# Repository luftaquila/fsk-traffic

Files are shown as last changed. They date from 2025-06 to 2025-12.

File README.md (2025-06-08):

# Formula Student Korea Traffic Controller

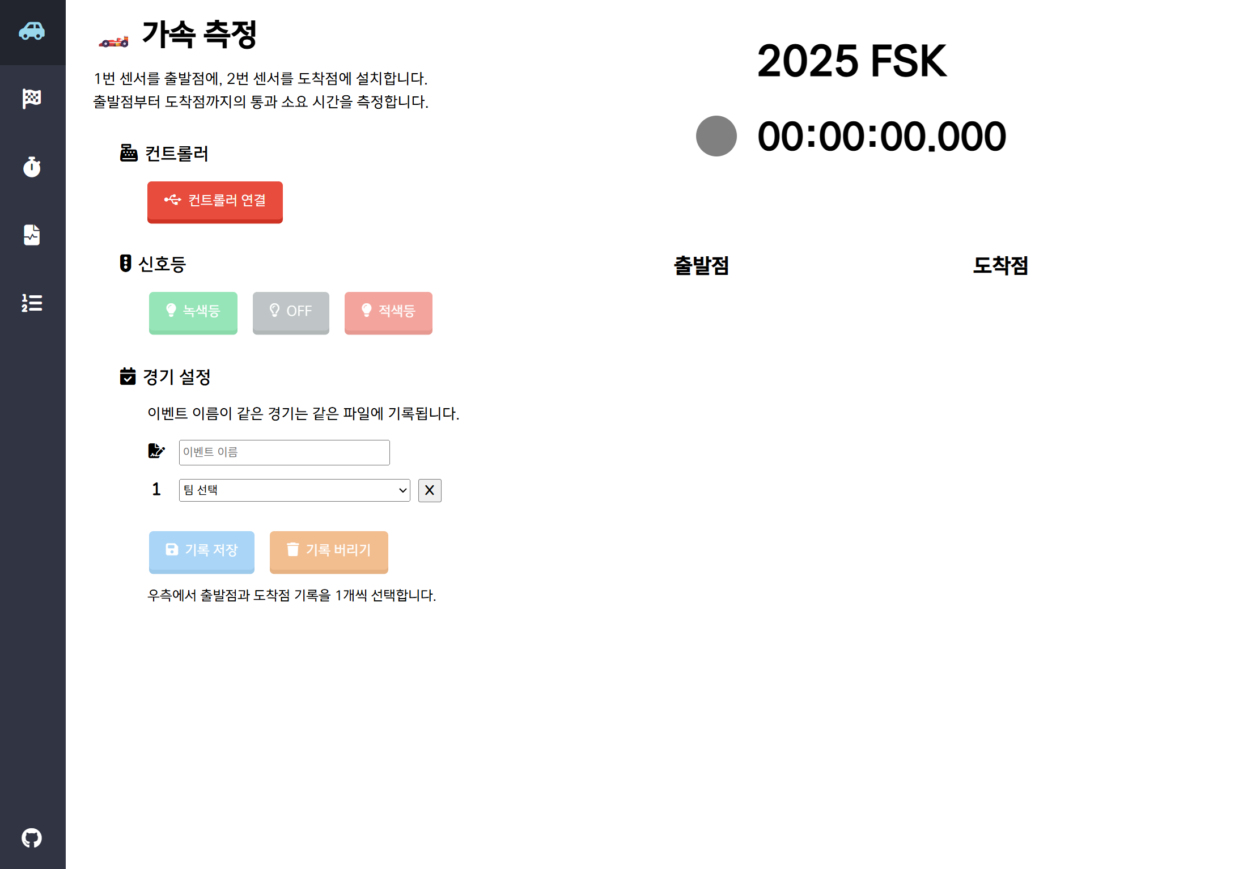
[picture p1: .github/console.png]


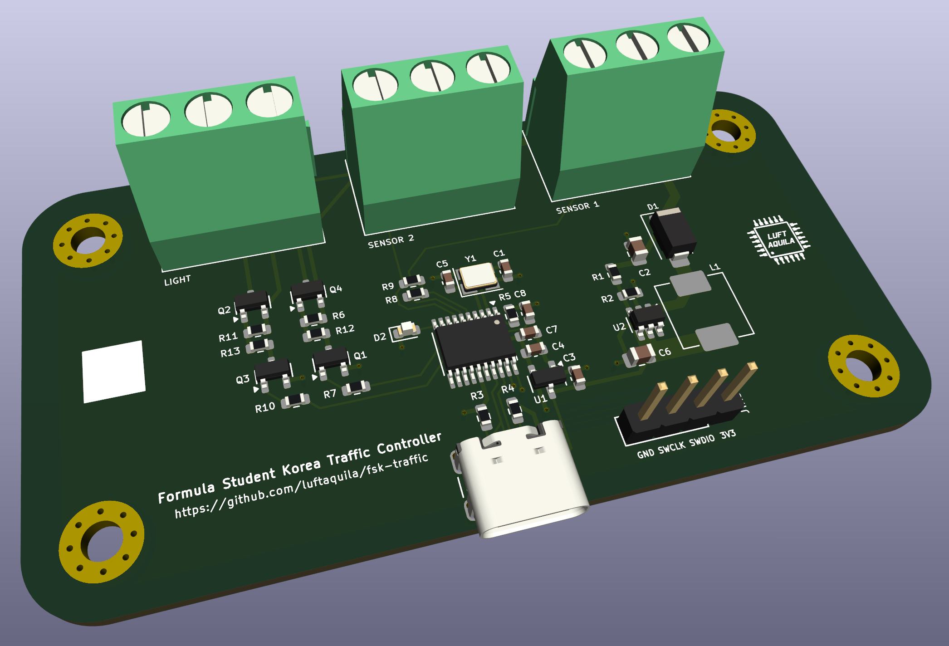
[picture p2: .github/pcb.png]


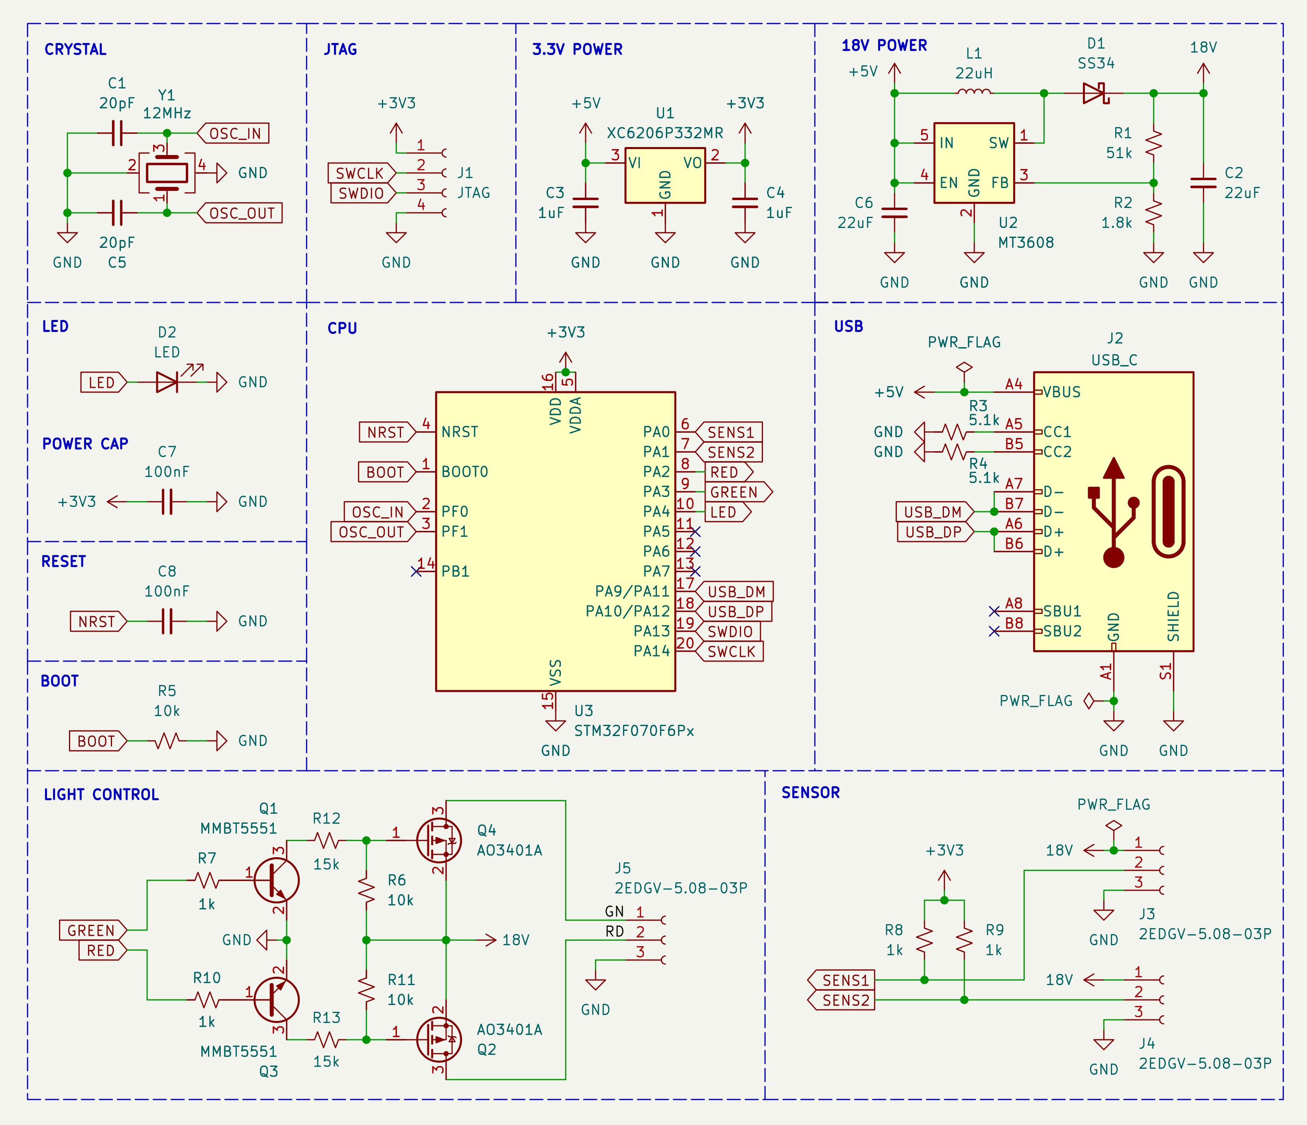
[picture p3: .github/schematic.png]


## Development

### Controller firmware

#### Prerequisites

```sh
git clone https://github.com/luftaquila/fsk-traffic.git
```

* `arm-none-eabi-gcc` ([AArch32 bare-metal target (arm-none-eabi)](https://developer.arm.com/downloads/-/arm-gnu-toolchain-downloads))
* make
* openocd

#### Build and upload

```sh
cd device/firmware
make program
```

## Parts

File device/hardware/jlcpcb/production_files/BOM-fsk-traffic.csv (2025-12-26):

Comment | Designator | Footprint | LCSC | Quantity
LTV-817S | U4,U5 | SMDIP-4_W9.53mm | C109227 | 2
100nF | C7,C8 | C_0603_1608Metric | C14663 | 2
AO3401A | Q2,Q4 | SOT-23 | C15127 | 2
1uF | C3,C4 | C_0603_1608Metric | C15849 | 2
470nF | C10,C9 | C_0603_1608Metric | C1623 | 2
20pF | C1,C5 | C_0603_1608Metric | C1648 | 2
USB_C | J2 | USB_C_Receptacle_GCT_USB4105-xx-A_16P_TopMnt_Horizontal | C165948 | 1
22uH | L1 | L_Changjiang_FXL0630 | C177244 | 1
1k | R10,R14,R7 | R_0603_1608Metric | C21190 | 3
MMBT5551 | Q1,Q3 | SOT-23 | C2145 | 2
15k | R12,R13 | R_0603_1608Metric | C22809 | 2
LED | D2 | LED_0603_1608Metric | C2286 | 1
2k | R15,R16 | R_0603_1608Metric | C22975 | 2
3.3k | R8,R9 | R_0603_1608Metric | C22978 | 2
5.1k | R3,R4 | R_0603_1608Metric | C23186 | 2
51k | R1 | R_0603_1608Metric | C23196 | 1
10k | R11,R5,R6 | R_0603_1608Metric | C25804 | 3
1.8k | R2 | R_0603_1608Metric | C4177 | 1
22uF | C2,C6 | C_0805_2012Metric | C45783 | 2
XC6206P332MR | U1 | SOT-23-3 | C5446 | 1
SS34 | D1 | D_SMA | C8678 | 1
STM32F070F6Px | U3 | TSSOP-20_4.4x6.5mm_P0.65mm | C86951 | 1
12MHz | Y1 | Crystal_SMD_3225-4Pin_3.2x2.5mm | C9002 | 1
MT3608 | U2 | SOT-23-6 |  | 1

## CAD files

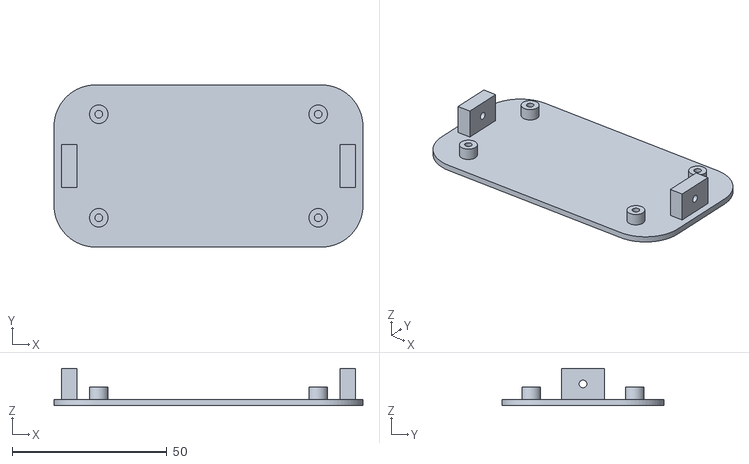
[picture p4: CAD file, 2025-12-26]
device/3d/base.stl
100.0 x 52.5 x 12.0

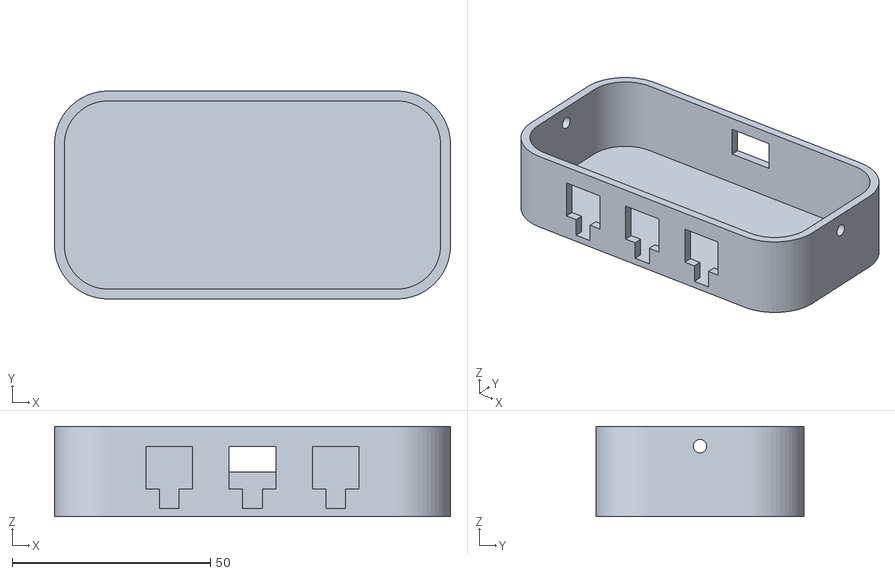
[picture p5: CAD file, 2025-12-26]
device/3d/lid.stl
100.0 x 52.5 x 22.8

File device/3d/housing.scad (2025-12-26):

// PCB Housing for 83x45.5mm board
// OpenSCAD design for 3D printing

/* [Rendering Options] */
// What to render
part = "both"; // [bottom, lid, both, assembled]

/* [PCB Dimensions] */
pcb_length = 83;        // mm
pcb_width = 45.5;       // mm
pcb_corner_r = 6;       // mm
pcb_thickness = 1.6;    // mm (standard PCB)

/* [Housing Dimensions] */
wall_thickness = 2.5;   // mm
floor_thickness = 2;    // mm
lid_thickness = 2;      // mm
pcb_clearance = 1;      // mm (gap between PCB and walls/mounting structures)

/* [Boss / Standoff] */
boss_height = 4;        // mm (PCB height from floor)
boss_outer_d = 6;       // mm
boss_inner_d = 2.5;     // mm (for M3 tap or insert)

/* [USB Type-C Port] */
usbc_width = 13;        // mm (with rubber boot clearance)
usbc_height = 7;        // mm (with rubber boot clearance)
// USB port position: 38.334mm from left, 39.566mm from right
// Offset from center = (38.334 - 39.566) / 2 = -0.616mm (shifted left)
usbc_x_offset = -0.616; // mm (negative = left when looking at port)
usbc_z_offset = -1.6;   // mm (negative = lower)

/* [Molex 5557 Connector] */
molex_width = 10.8;     // mm
molex_height = 10.2;    // mm (protrusion from wall)
molex_depth = 14;       // mm (along PCB direction)
molex_spacing = 10.2;   // mm (center to center gap between connectors)
molex_latch_extra = 5;  // mm (extra height for latch)
molex_labels = ["LIGHT", "SENS2", "SENS1"];  // labels for each connector
label_size = 3.0;       // mm (text height)
label_depth = 0.8;      // mm (engraving depth)
label_spacing = 1.2;    // character spacing (1 = normal, >1 = wider)
label_weight = -0.05;   // mm (0 = normal, + = thicker, - = thinner)

/* [Lid Mounting] */
mount_wall_width = 14;       // mm (Y direction)
mount_wall_thickness = 5;    // mm (X direction, for screw thread)
mount_wall_height = 10;      // mm (Z direction)
mount_screw_d = 2.5;         // mm (for M3 tap)

/* [Calculated Values] */
// PCB cavity (where PCB sits, with clearance all around)
pcb_cavity_length = pcb_length + pcb_clearance * 2;
pcb_cavity_width = pcb_width + pcb_clearance * 2;

// Housing dimensions (includes mounting wall space at short sides)
inner_length = pcb_cavity_length + mount_wall_thickness * 2;
inner_width = pcb_cavity_width;
outer_length = inner_length + wall_thickness * 2;
outer_width = inner_width + wall_thickness * 2;

// Height from floor to PCB top surface
pcb_top_z = boss_height + pcb_thickness;

// Total internal height
component_height = max(molex_height + molex_latch_extra, 15);
inner_height = boss_height + pcb_thickness + component_height;
outer_height = floor_thickness + inner_height + lid_thickness;

// M3 hole positions (at corner radius centers, relative to PCB center)
m3_positions = [
    [pcb_corner_r - pcb_length/2, pcb_corner_r - pcb_width/2],
    [pcb_length/2 - pcb_corner_r, pcb_corner_r - pcb_width/2],
    [pcb_corner_r - pcb_length/2, pcb_width/2 - pcb_corner_r],
    [pcb_length/2 - pcb_corner_r, pcb_width/2 - pcb_corner_r]
];

// Molex connector positions (X offset from center)
molex_positions = [
    -molex_spacing - molex_width,
    0,
    molex_spacing + molex_width
];

$fn = 64;

// ============================================
// MODULES
// ============================================

module rounded_rect(length, width, r) {
    offset(r = r)
        offset(r = -r)
            square([length, width], center = true);
}

module rounded_box(length, width, height, r) {
    linear_extrude(height)
        rounded_rect(length, width, r);
}

module boss() {
    difference() {
        cylinder(h = boss_height, d = boss_outer_d);
        cylinder(h = boss_height + 1, d = boss_inner_d);
    }
}

// ============================================
// BOTTOM PART
// ============================================

module bottom() {
    difference() {
        union() {
            // Floor plate (same size as lid)
            rounded_box(outer_length, outer_width, floor_thickness, pcb_corner_r + wall_thickness + mount_wall_thickness);
            
            // Boss standoffs for PCB
            translate([0, 0, floor_thickness]) {
                for (pos = m3_positions) {
                    translate([pos[0], pos[1], 0])
                        boss();
                }
            }
            
            // Mounting walls (inside lid walls, outside PCB cavity)
            // Left side
            translate([-pcb_cavity_length/2 - mount_wall_thickness, -mount_wall_width/2, floor_thickness])
                cube([mount_wall_thickness, mount_wall_width, mount_wall_height]);
            
            // Right side
            translate([pcb_cavity_length/2, -mount_wall_width/2, floor_thickness])
                cube([mount_wall_thickness, mount_wall_width, mount_wall_height]);
        }
        
        // Horizontal screw holes in mounting walls (threaded)
        screw_z = floor_thickness + mount_wall_height / 2;
        
        // Left wall hole
        translate([-outer_length/2 - 1, 0, screw_z])
            rotate([0, 90, 0])
                cylinder(h = wall_thickness + mount_wall_thickness + 2, d = mount_screw_d);
        
        // Right wall hole
        translate([pcb_cavity_length/2 - 1, 0, screw_z])
            rotate([0, 90, 0])
                cylinder(h = wall_thickness + mount_wall_thickness + 2, d = mount_screw_d);
    }
}

// ============================================
// LID PART
// ============================================

module lid() {
    m3_clearance = 3.4;
    screw_z = mount_wall_height / 2;
    port_margin = 0.5;  // extra clearance for ports
    
    difference() {
        union() {
            // Top plate
            translate([0, 0, inner_height])
                rounded_box(outer_length, outer_width, lid_thickness, pcb_corner_r + wall_thickness + mount_wall_thickness);
            
            // Side walls
            difference() {
                rounded_box(outer_length, outer_width, inner_height, pcb_corner_r + wall_thickness + mount_wall_thickness);
                translate([0, 0, -0.1])
                    rounded_box(inner_length, inner_width, inner_height + 0.2, pcb_corner_r + mount_wall_thickness);
            }
        }
        
        // USB Type-C port cutout (offset from center)
        // Port starts at PCB top surface and goes UP
        translate([usbc_x_offset - usbc_width/2, -outer_width/2 - 1, pcb_top_z + usbc_z_offset - port_margin])
            cube([usbc_width, wall_thickness + 2, usbc_height + port_margin * 2]);
        
        // Molex 5557 connector cutouts
        // Port starts at PCB top surface and goes UP
        molex_latch_width = 5;  // latch opening width (center only)
        for (x_pos = molex_positions) {
            // Main connector opening (full width)
            translate([x_pos - (molex_width + 1)/2, outer_width/2 - wall_thickness - 1, pcb_top_z - port_margin])
                cube([molex_width + 1, wall_thickness + 2, molex_height + port_margin]);
            
            // Latch opening (center 5mm only, exactly molex_latch_extra height)
            translate([x_pos - molex_latch_width/2, outer_width/2 - wall_thickness - 1, pcb_top_z + molex_height])
                cube([molex_latch_width, wall_thickness + 2, molex_latch_extra]);
        }
        
        // Horizontal screw holes through short side walls (clearance holes)
        // Left wall
        translate([-outer_length/2 - 1, 0, screw_z])
            rotate([0, 90, 0])
                cylinder(h = wall_thickness + 2, d = m3_clearance);
        
        // Right wall
        translate([outer_length/2 - wall_thickness - 1, 0, screw_z])
            rotate([0, 90, 0])
                cylinder(h = wall_thickness + 2, d = m3_clearance);
        
        // Molex connector labels (engraved on top surface)
        for (i = [0:2]) {
            translate([molex_positions[i], outer_width/2 - wall_thickness - 5, inner_height + lid_thickness - label_depth + 0.1])
                linear_extrude(label_depth + 0.1)
                    offset(r = label_weight)
                        text(molex_labels[i], size = label_size, spacing = label_spacing, halign = "center", valign = "center", font = "Liberation Sans:style=Bold");
        }
    }
}

// ============================================
// RENDERING
// ============================================

if (part == "bottom") {
    bottom();
}
else if (part == "lid") {
    translate([0, 0, inner_height + lid_thickness])
        rotate([180, 0, 0])
            lid();
}
else if (part == "both") {
    translate([-(outer_length/2 + 10), 0, 0])
        bottom();
    
    translate([outer_length/2 + 10, 0, inner_height + lid_thickness])
        rotate([180, 0, 0])
            lid();
}
else if (part == "assembled") {
    color("lightblue", 0.8) bottom();
    
    color("lightyellow", 0.8)
    translate([0, 0, floor_thickness])
        lid();
}

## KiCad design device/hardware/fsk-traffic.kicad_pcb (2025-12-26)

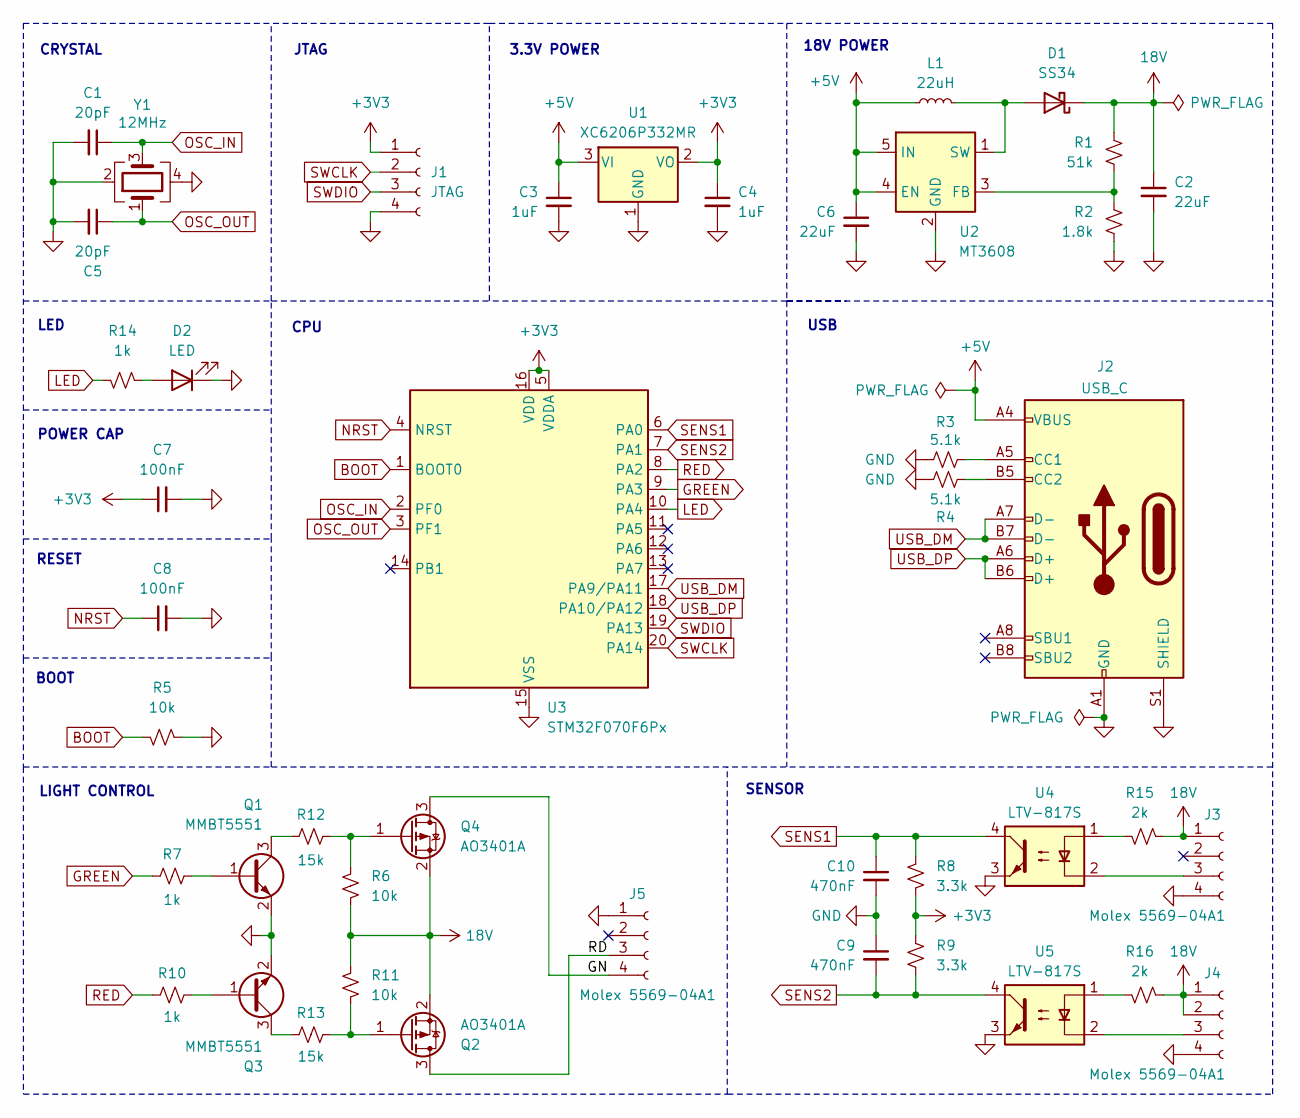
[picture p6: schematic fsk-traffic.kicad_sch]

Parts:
C1, C5: 20pF; C_0603_1608Metric; LCSC C1648
C2, C6: 22uF; C_0805_2012Metric; LCSC C45783
C3, C4: 1uF; C_0603_1608Metric; LCSC C15849
C7, C8: 100nF; C_0603_1608Metric; LCSC C14663
C9, C10: 470nF; C_0603_1608Metric; LCSC C1623
D1: SS34; D_SMA; LCSC C8678
D2: LED; LED_0603_1608Metric; LCSC C2286
J1: JTAG; PinHeader_1x04_P2.54mm_Vertical
J2: USB_C; USB_C_Receptacle_GCT_USB4105-xx-A_16P_TopMnt_Horizontal; LCSC C165948
J3, J4, J5: Molex 5569-04A1; Molex_Mini-Fit_Jr_5569-04A1_2x02_P4.20mm_Horizontal
L1: 22uH; L_Changjiang_FXL0630; LCSC C177244
Q1, Q3: MMBT5551; SOT-23; LCSC C2145
Q2, Q4: AO3401A; SOT-23; LCSC C15127
R1: 51k; R_0603_1608Metric; LCSC C23196
R2: 1.8k; R_0603_1608Metric; LCSC C4177
R3, R4: 5.1k; R_0603_1608Metric; LCSC C23186
R5, R6, R11: 10k; R_0603_1608Metric; LCSC C25804
R7, R10, R14: 1k; R_0603_1608Metric; LCSC C21190
R8, R9: 3.3k; R_0603_1608Metric; LCSC C22978
R12, R13: 15k; R_0603_1608Metric; LCSC C22809
R15, R16: 2k; R_0603_1608Metric; LCSC C22975
U1: XC6206P332MR; SOT-23-3; LCSC C5446
U2: MT3608; SOT-23-6; LCSC C2932326
U3: STM32F070F6Px; TSSOP-20_4.4x6.5mm_P0.65mm; LCSC C86951
U4, U5: LTV-817S; SMDIP-4_W9.53mm; LCSC C109227
Y1: 12MHz; Crystal_SMD_3225-4Pin_3.2x2.5mm; LCSC C9002

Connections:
18V: C2.1, D1.1 (K), J3.1, J4.1, J4.2, Q2.2 (S), Q4.2 (S), R1.1, R6.2, R11.1, R15.1, R16.1
+3V3: C4.1, C7.1, J1.1, R8.2, R9.1, U1.2 (VO), U3.5 (VDDA), U3.16 (VDD)
+5V: C3.1, C6.1, J2.A4 (VBUS), J2.A9 (VBUS), J2.B4 (VBUS), J2.B9 (VBUS), L1.1, U1.3 (VI), U2.4 (EN), U2.5 (IN)
/GN: J5.4, Q4.3 (D)
/RD: J5.3, Q2.3 (D)
BOOT: R5.2, U3.1 (BOOT0)
GND: C1.2, C2.2, C3.2, C4.2, C5.2, C6.2, C7.2, C8.2, C9.1, C10.2, D2.1 (K), J1.4, J2.A1 (GND), J2.A12 (GND), J2.B1 (GND), J2.B12 (GND), J2.S1 (SHIELD), J3.4, J4.4, J5.1, Q1.2 (E), Q3.2 (E), R2.2, R3.1, R4.1, R5.1, U1.1 (GND), U2.2 (GND), U3.15 (VSS), U4.3, U5.3, Y1.2, Y1.4
GREEN: R7.2, U3.9 (PA3)
LED: R14.2, U3.10 (PA4)
NRST: C8.1, U3.4 (NRST)
unnamed: D1.2 (A), L1.2, U2.1 (SW)
unnamed: D2.2 (A), R14.1
unnamed: J2.A5 (CC1), R3.2
unnamed: J2.B5 (CC2), R4.2
unnamed: J3.3, U4.2
unnamed: J4.3, U5.2
unnamed: Q1.1 (B), R7.1
unnamed: Q1.3 (C), R12.2
unnamed: Q2.1 (G), R11.2, R13.1
unnamed: Q3.1 (B), R10.1
unnamed: Q3.3 (C), R13.2
unnamed: Q4.1 (G), R6.1, R12.1
unnamed: R15.2, U4.1
unnamed: R16.2, U5.1
unnamed: R1.2, R2.1, U2.3 (FB)
OSC_IN: C1.1, U3.2 (PF0), Y1.3
OSC_OUT: C5.1, U3.3 (PF1), Y1.1
RED: R10.2, U3.8 (PA2)
SENS1: C10.1, R8.1, U3.6 (PA0), U4.4
SENS2: C9.2, R9.2, U3.7 (PA1), U5.4
SWCLK: J1.2, U3.20 (PA14)
SWDIO: J1.3, U3.19 (PA13)
USB_DM: J2.A7 (D-), J2.B7 (D-), U3.17 (PA9/PA11)
USB_DP: J2.A6 (D+), J2.B6 (D+), U3.18 (PA10/PA12)

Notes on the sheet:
SENSOR
3.3V POWER
LIGHT CONTROL
POWER CAP
CPU
JTAG
18V POWER
RESET
BOOT
LED
CRYSTAL
USB

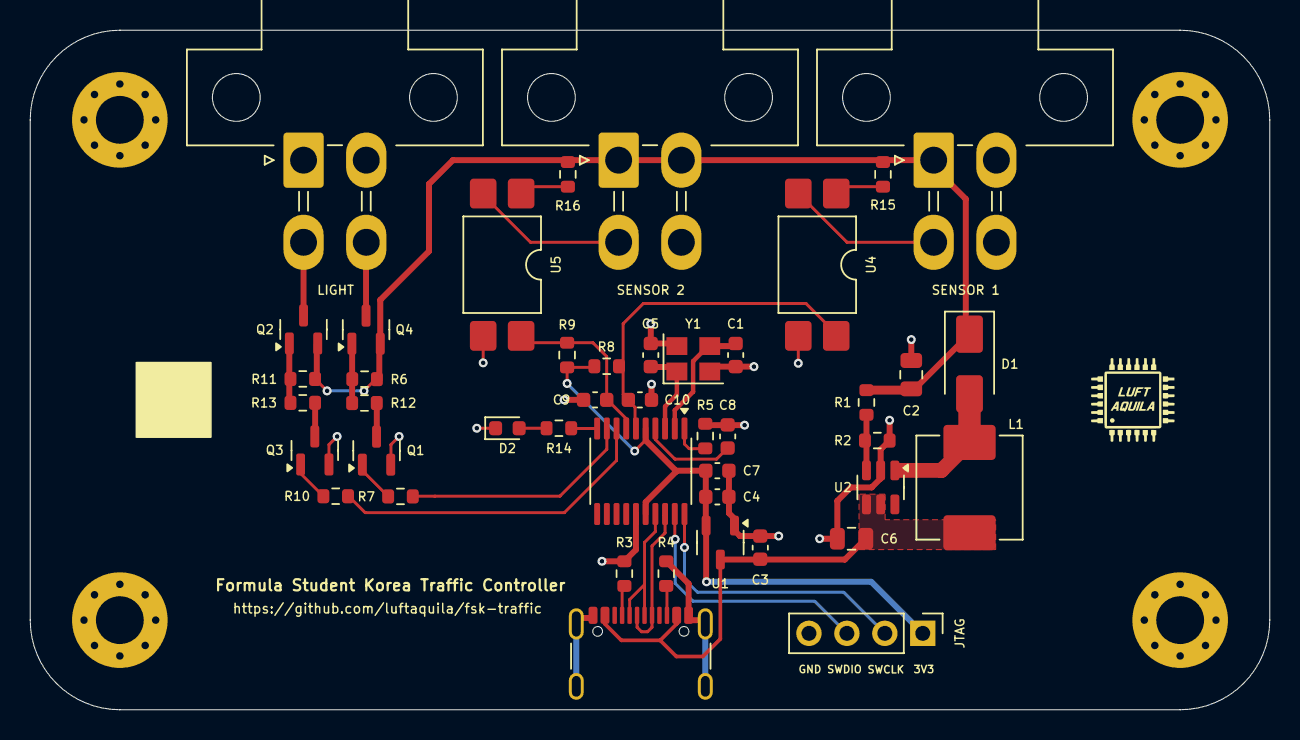
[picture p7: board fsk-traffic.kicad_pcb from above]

Board: 2 copper layers, 83.0 x 45.5 mm, 44 parts (0 on the bottom side), 34 nets.

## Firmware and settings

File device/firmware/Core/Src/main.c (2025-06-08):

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
/* Includes ------------------------------------------------------------------*/
#include "main.h"
#include "usb_device.h"
#include "gpio.h"

/* USER CODE BEGIN Includes */
#include "usbd_cdc_if.h"
/* USER CODE END Includes */


/* USER CODE BEGIN PV */
/* USB buffer and flag */
volatile uint32_t usb_rcv_flag = false;
extern uint8_t UserRxBufferFS[];
extern uint8_t UserTxBufferFS[];

volatile uint32_t sensor_flag = false;
uint32_t sensor_tick[2];

const char usb_cmd[][3] = {
  "$H", // HELLO
  "$G", // GREEN
  "$R", // RED
  "$X", // OFF
  "$R", // RESET
};
/* USER CODE END PV */

void SystemClock_Config(void);
/* USER CODE BEGIN 0 */
void HAL_GPIO_EXTI_Callback(uint16_t GPIO_Pin) {
  uint32_t tick = HAL_GetTick();

  switch (GPIO_Pin) {
    case SENS1_Pin:
      if (tick - sensor_tick[0] > 200) {
        sensor_flag |= 1 << 0;
        sensor_tick[0] = tick;
      }
      break;
    case SENS2_Pin:
      if (tick - sensor_tick[1] > 200) {
        sensor_flag |= 1 << 1;
        sensor_tick[1] = HAL_GetTick();
      }
      break;
    default:
      break;
  }
}
/* USER CODE END 0 */

/**
  * @brief  The application entry point.
  * @retval int
  */
int main(void)
{

  /* MCU Configuration--------------------------------------------------------*/

  /* Reset of all peripherals, Initializes the Flash interface and the Systick. */
  HAL_Init();

  /* Configure the system clock */
  SystemClock_Config();

  /* Initialize all configured peripherals */
  MX_GPIO_Init();
  MX_USB_DEVICE_Init();
  /* USER CODE BEGIN 2 */
  // flash traffic light 3 times
  for (int i = 0; i < 6; i++) {
    // on at even, off at odd
    RED(!(i & 0b01));
    GREEN(!(i & 0b01));
    HAL_GPIO_TogglePin(LED_GPIO_Port, LED_Pin);
    HAL_Delay(200);
  }

  HAL_GPIO_WritePin(LED_GPIO_Port, LED_Pin, GPIO_PIN_SET);
  /* USER CODE END 2 */

  /* Infinite loop */
  /* USER CODE BEGIN WHILE */
  while (true) {
    if (sensor_flag) {
      if (sensor_flag & (1 << 0)) {
        sprintf((char *)UserTxBufferFS, "$S 1 %lu!\n", sensor_tick[0]);
        USB_Transmit(UserTxBufferFS);
        sensor_flag &= ~(1 << 0);
      }

      if (sensor_flag & (1 << 1)) {
        sprintf((char *)UserTxBufferFS, "$S 2 %lu!\n", sensor_tick[1]);
        USB_Transmit(UserTxBufferFS);
        sensor_flag &= ~(1 << 1);
      }
    }

    if (usb_rcv_flag) {
      if (USB_Command(CMD_GREEN)) {
        GREEN(true);
        RED(false);
        sprintf((char *)UserTxBufferFS, "$OK G %lu!\n", HAL_GetTick());
        USB_Transmit(UserTxBufferFS);
      } else if (USB_Command(CMD_RED)) {
        GREEN(false);
        RED(true);
        USB_Transmit("$OK R!\n");
      } else if (USB_Command(CMD_OFF)) {
        GREEN(false);
        RED(false);
        USB_Transmit("$OK X!\n");
      } else if (USB_Command(CMD_RESET)) {
        HAL_NVIC_SystemReset();
      } else if (USB_Command(CMD_HELLO)) {
        USB_Transmit("$HI!\n");
      } else {
        USB_Transmit("$E!\n");
      }

      usb_rcv_flag = false;
      HAL_GPIO_WritePin(LED_GPIO_Port, LED_Pin, GPIO_PIN_SET);
    }
    /* USER CODE END WHILE */

    /* USER CODE BEGIN 3 */
  }
  /* USER CODE END 3 */
}

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


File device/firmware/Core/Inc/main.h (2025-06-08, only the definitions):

#define SENS1_Pin GPIO_PIN_0
#define SENS1_GPIO_Port GPIOA
#define SENS1_EXTI_IRQn EXTI0_1_IRQn
#define SENS2_Pin GPIO_PIN_1
#define SENS2_GPIO_Port GPIOA
#define SENS2_EXTI_IRQn EXTI0_1_IRQn
#define RED_Pin GPIO_PIN_2
#define RED_GPIO_Port GPIOA
#define GREEN_Pin GPIO_PIN_3
#define GREEN_GPIO_Port GPIOA
#define LED_Pin GPIO_PIN_4
#define LED_GPIO_Port GPIOA
#define true  (1)
#define false (0)

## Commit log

2025-03-12 remove: sensor firmware
    [fsk-traffic-control.cfg, fsk-traffic-sensor-base.stl, fsk-traffic-sensor-top.stl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]
2025-03-16 update: set sensor input pins
2025-03-18 update: new firmware with wired sensors
    [fsk-traffic-control.cfg, fsk-traffic-controller-base.stl, fsk-traffic-controller-top.stl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]
2025-03-18 improve: fixed length usb cmd
    [main.h]
2025-03-18 fix: usb recv flag
    [main.c, main.h]
2025-03-18 fix: sensor detection bugs
    [main.c]
2025-03-23 add: schematics
    [fsk-traffic-control.kicad_pcb, fsk-traffic-control.kicad_sch]
2025-05-13 update: replace MCU to STM32F070F6P6
    [fsk-traffic-control.cfg]
2025-05-13 update: make and openocd script
    [fsk-traffic.cfg]
2025-05-14 add: final PCB and gerber
    [BOM-fsk-traffic.csv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]
2025-06-05 fix: missing pullup on PNP base cause overcurrent
    [fsk-traffic.kicad_sch]
2025-06-05 update: PCB v2
    fix SSR Hi-side driver and MT3608 layout
    [BOM-fsk-traffic.csv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]
2025-06-08 fix: add resistor divider to protect PMOS
    [BOM-fsk-traffic.csv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]
2025-06-18 fix: misc pcb bugs
    [BOM-fsk-traffic.csv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]
2025-09-02 add: pcb workflow
2025-09-02 update: 3d model
    [base.stl, fsk-traffic-controller-base.stl, fsk-traffic-controller-top.stl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]
2025-10-27 fix: isolation & filter
    [BOM-fsk-traffic.csv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]
2025-12-25 fix: error handling on device disconnection
2025-12-26 add: housing scad
    [base.stl, housing.scad, lid.stl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]
2025-12-26 fix: missing pcb 18V wiring
    [fsk-traffic.kicad_pcb]
2025-12-26 update: remove MT3608 from SMT due to JLC chip misbehavior
    [BOM-fsk-traffic.csv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]
2025-12-26 update: latch and engrave depth
    [base.stl, housing.scad, lid.stl]

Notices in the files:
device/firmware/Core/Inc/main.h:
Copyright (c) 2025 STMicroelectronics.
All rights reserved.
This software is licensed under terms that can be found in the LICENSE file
